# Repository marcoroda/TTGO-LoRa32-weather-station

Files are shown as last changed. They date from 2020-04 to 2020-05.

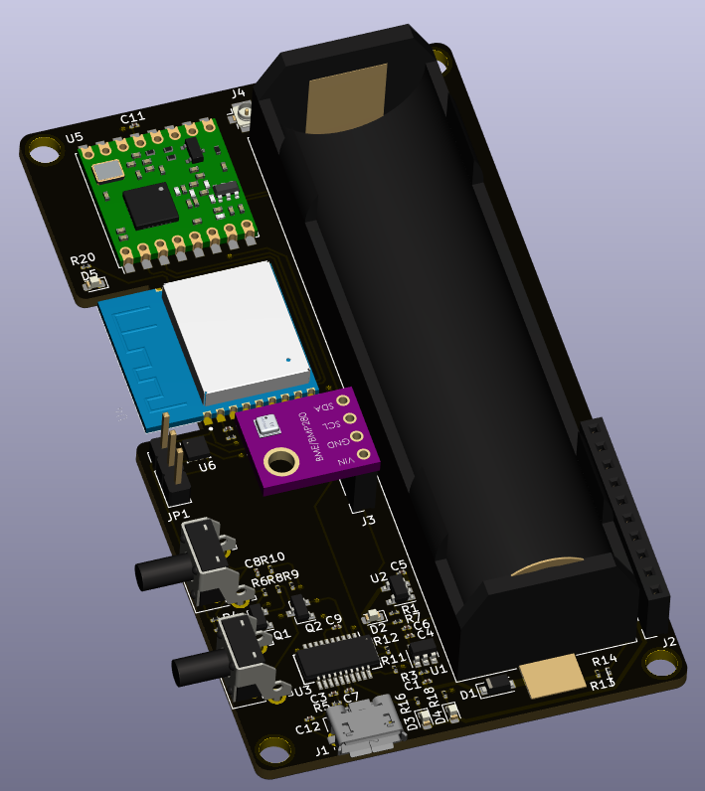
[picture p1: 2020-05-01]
hw/pcb/img/3d_pcb.png

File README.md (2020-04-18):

# ttgo-LoRa-weatherStation
TTGO board hooked up with BME280 and connected to TTN through LoRa.

* /hw : Hardware related (PCB, Schematics, 3D case, etc).
* /src : PlatformIO project.
* /node-RED : node-RED app retrieving LoRa payload from The Things Network

Project documentation [here](https://marcoroda.com/2020/04/12/TTGO-LORA-TTN.html)

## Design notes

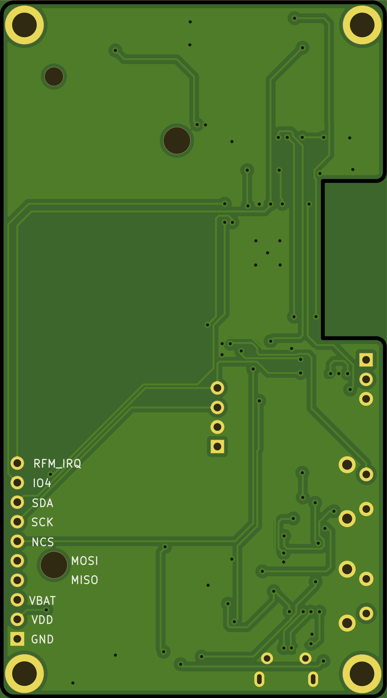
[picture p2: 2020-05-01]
hw/pcb/LoRa_node_WeatherStation/plot/LoRa_node_WeatherStation-Back.png

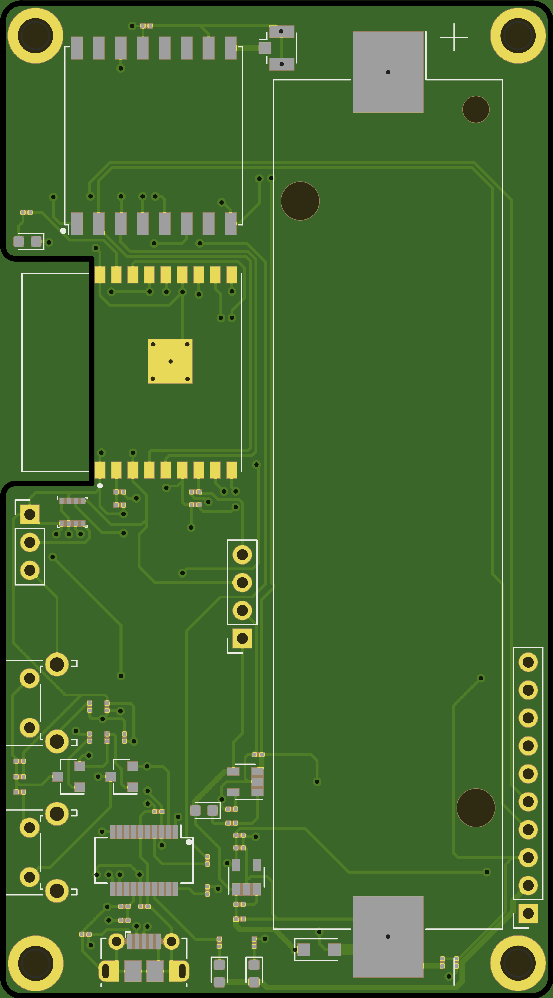
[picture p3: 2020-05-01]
hw/pcb/LoRa_node_WeatherStation/plot/LoRa_node_WeatherStation-Front.png

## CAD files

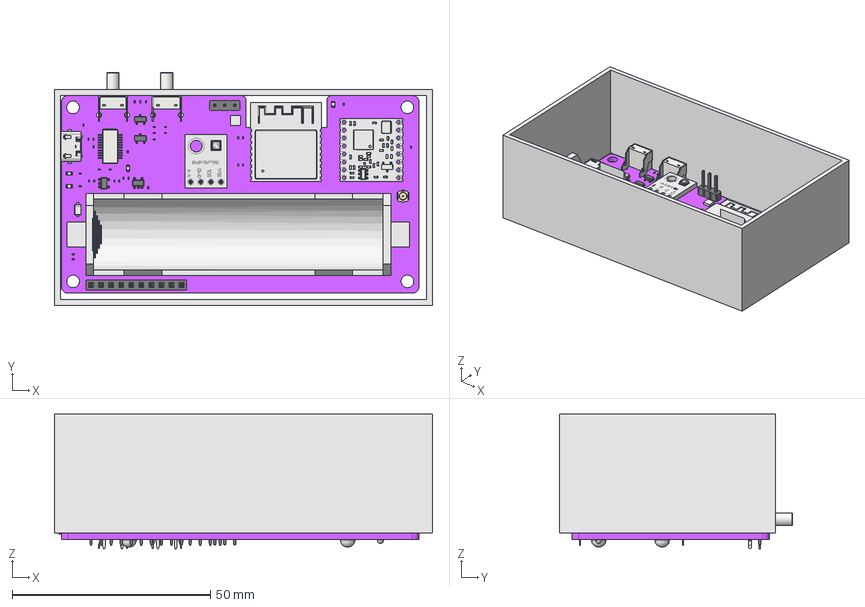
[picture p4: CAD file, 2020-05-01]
hw/3d_enclosure/3d_enclosure.FCStd
95.4 x 58.8 x 34.0 mm
Pcb
C7_C_0201_0603Metric_5EA9F067
BT1_BatteryHolder_Keystone_1042_1x18650_5EA9C623
C1_C_0201_0603Metric_5EA9C634
C2_C_0201_0603Metric_5EAA4A3B
C3_C_0201_0603Metric_5EA9C656
C5_C_0201_0603Metric_5EA9C678
C6_C_0201_0603Metric_5EA9C689
C8_C_0201_0603Metric_5EA9C6AB
C9_C_0201_0603Metric_5EA9C6BC
C10_C_0201_0603Metric_5EA9C6CD
C11_C_0201_0603Metric_5EA9C6DE
D1_D_SOD_123F_5EA9C6F7
D2_LED_0603_1608Metric_5EA9C70A
D3_LED_0603_1608Metric_5EA9C71D
D4_LED_0603_1608Metric_5EAA3DA1
D5_LED_0603_1608Metric_5EA9C743
J2_PinSocket_1x10_P254mm_Vertical_5EA9C781
J3_PinSocket_1x04_P254mm_Vertical_5EAA5ACD
J3_User Library-GY-BME280_5EAA5ACD[2]
JP1_PinHeader_1x03_P254mm_Vertical_5EA9C7B0
Q1_SOT_23_5EAA5330
Q2_SOT_23_5EA9C7DA
R1_R_0201_0603Metric_5EAA9D60
R2_R_0201_0603Metric_5EA9C7FC
R3_R_0201_0603Metric_5EA9C80D
R4_R_0201_0603Metric_5EAA4BE8
R5_R_0201_0603Metric_5EA9C82F
R6_R_0201_0603Metric_5EA9C840
R7_R_0201_0603Metric_5EA9C851
R8_R_0201_0603Metric_5EA9C862
R9_R_0201_0603Metric_5EA9C873
R10_R_0201_0603Metric_5EA9C884
R11_R_0201_0603Metric_5EA9C895
R12_R_0201_0603Metric_5EAA3F9B
R18_R_0201_0603Metric_5EAA3AF5
R17_R_0201_0603Metric_5EA9C8C8
R19_R_0201_0603Metric_5EA9C8D9
R20_R_0201_0603Metric_5EA9C8EA
R15_R_0201_0603Metric_5EA9C8FB
R13_R_0201_0603Metric_5EA9C90C
R14_R_0201_0603Metric_5EA9C91D
SW1_SW_Tactile_SPST_Angled_PTS645Vx83-2LFS_5EA9C943
SW2_SW_Tactile_SPST_Angled_PTS645Vx83-2LFS_5EAA43DF
U1_SOT_23_5_5EAA80A0
U2_SOT_23_5_5EA9C993
U3_SSOP_20_39x87mm_P0635mm_5EA9C9BC
U4_ESP-WROOM-02D--3DModel-STEP-56544_5EA9C9F2
U5_User Library-RFM96W_5EA9CA17[2]
U6_Bosch_LGA_8_25x25mm_P065mm_ClockwisePinNumbering_5EA9CA34
C4_C_0201_0603Metric_5EA9E3E5
J1_475890001_5EAA57F6[2]
R16_R_0201_0603Metric_5EAA3B67
J4_U.FL_Hirose_U.FL-R-SMT-1_Vertical_5EAA1C61
C12_C_0201_0603Metric_5EAA570B

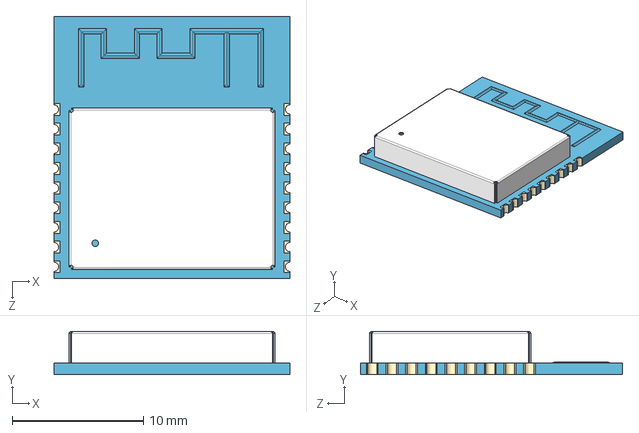
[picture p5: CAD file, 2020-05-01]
hw/3d_models/ESP-WROOM-02D--3DModel-STEP-56544.STEP
18.0 x 3.30 x 20.0 mm

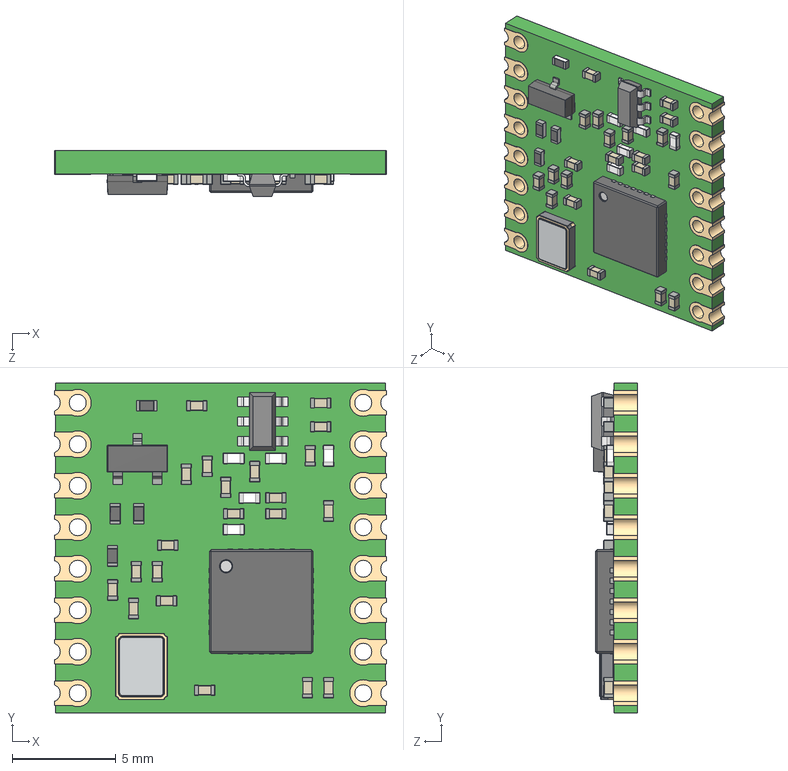
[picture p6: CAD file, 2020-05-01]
hw/3d_models/User Library-RFM96W/User Library-RFM96W.STEP
16.0 x 15.9 x 2.23 mm
Board
Cap0402 x 21
SW3dPS-inductor_0402_white x 5
SW3dPS-SOT-23-6
QFN28
TXC_7M
Res0402 x 4
User_Library-3-lead_sot23-3
Goldcontact x 16

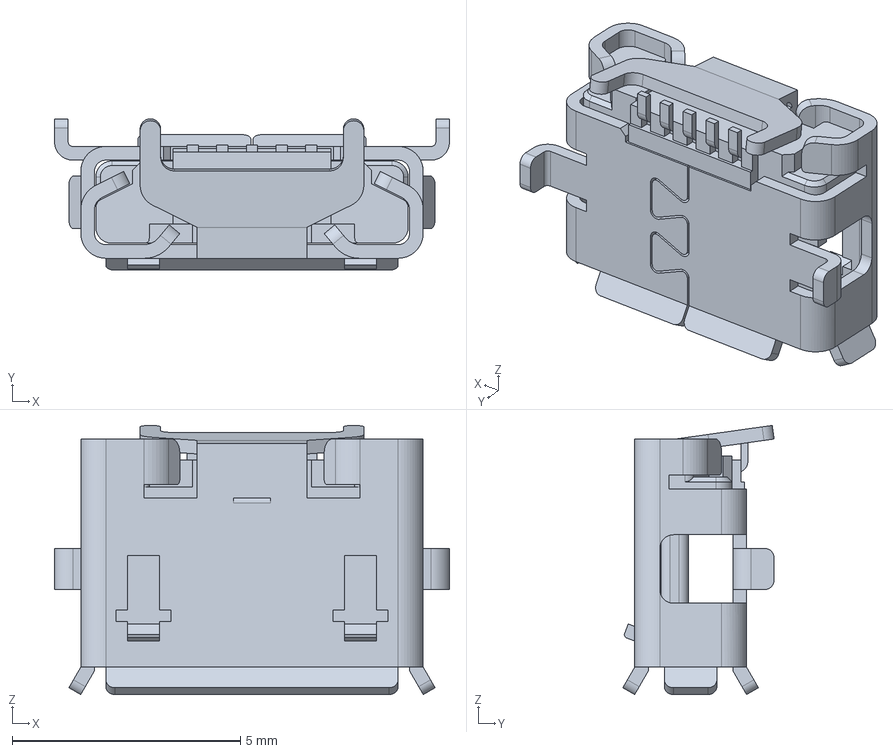
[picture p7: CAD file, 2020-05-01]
hw/3d_models/47589-0001_stp/475890001.stp
8.65 x 3.31 x 5.89 mm

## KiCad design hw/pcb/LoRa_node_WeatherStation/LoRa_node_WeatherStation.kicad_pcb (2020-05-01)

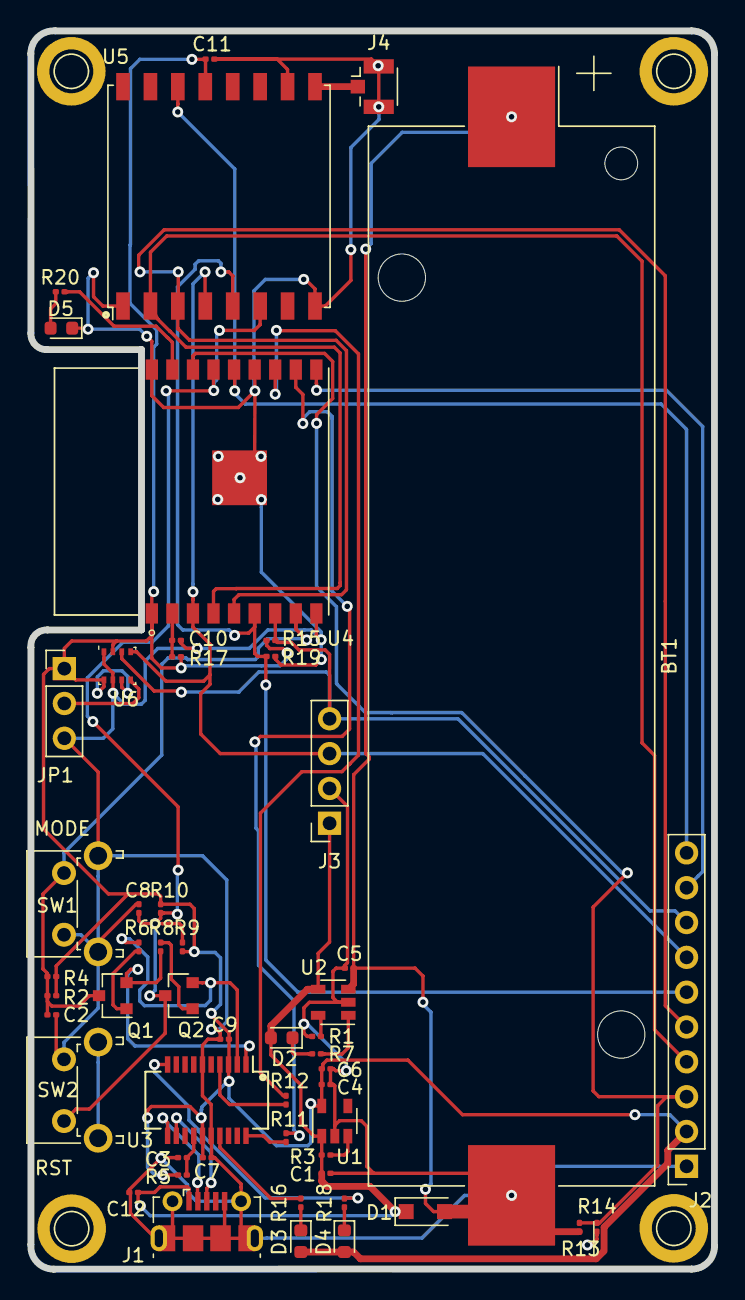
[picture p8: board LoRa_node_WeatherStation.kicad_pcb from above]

Board: 2 copper layers, 49.9 x 90.3 mm, 53 parts (0 on the bottom side), 38 nets.

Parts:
BT1: Battery_Cell; BatteryHolder_Keystone_1042_1x18650
C1, C4, C5, C9, C11: 10uF; C_0201_0603Metric
C2, C3, C7, C8, C10: 100nF; C_0201_0603Metric
C6: 1uF; C_0201_0603Metric
C12: 0.1uF; C_0201_0603Metric
D1: MBR120; D_SOD-123F
D2: ORANGE_LED; LED_0603_1608Metric
D3, D4: Blue_LED; LED_0603_1608Metric
D5: RED_LED; LED_0603_1608Metric
J1: USB_B_Micro; USB_Micro-B_Molex-105017-0001
J2: Conn_01x10; PinSocket_1x10_P2.54mm_Vertical
J3: BME breakout; PinSocket_1x04_P2.54mm_Vertical
J4: Conn_Coaxial; U.FL_Hirose_U.FL-R-SMT-1_Vertical
JP1: I2C slave Addr; PinHeader_1x03_P2.54mm_Vertical
Q1, Q2: BC848; SOT-23
R1, R2, R4, R5, R6, R8, R9, R10, R13, R14, R15, R17, R19: 10k; R_0201_0603Metric
R3: 100k; R_0201_0603Metric
R7, R16, R18, R20: 1k; R_0201_0603Metric
R11, R12: 470R; R_0201_0603Metric
SW1: MODE; SW_Tactile_SPST_Angled_PTS645Vx83-2LFS
SW2: RST; SW_Tactile_SPST_Angled_PTS645Vx83-2LFS
U1: SPX3819M5-L-3-3; SOT-23-5
U2: MCP73831-2-OT; SOT-23-5
U3: FT231XS; SSOP-20_3.9x8.7mm_P0.635mm
U4: ESP-WROOM-02; MODULE_ESP-WROOM-02
U5: RFM95W-868S2; HOPERF_RFM9XW_SMD
U6: BME280; Bosch_LGA-8_2.5x2.5mm_P0.65mm_ClockwisePinNumbering

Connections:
+BATT: BT1.1, C5.2, D1.2, R13.1, U2.3
/ADC: J2.3, R13.2, R14.1, U4.16
/ANT: J4.1, U5.9
/D+: J1.3, U3.12
/D-: J1.2, U3.11
/DTR: Q1.2, R8.1, U3.1
/IO0: C2.1, Q1.3, R2.1, R4.2, SW1.2, U4.8
/IO4: J2.9, U4.10
/IO16: R20.2, U4.17
/MISO: J2.4, U4.4, U5.2
/MOSI: J2.5, U4.5, U5.3
/RFM95_IRQ: J2.10, U4.14, U5.14
/RFM95_NSS: J2.6, R19.1, U4.6, U5.5
/RST: C8.1, Q2.3, R9.2, R10.1, SW2.1, U4.15, U5.6
/RTS: Q2.2, R6.1, U3.2
/RXD: R12.1, U4.12
/SCK: J2.7, J3.3, U4.3, U5.4, U6.4
/SDA: J2.8, J3.4, R15.2, U4.7, U6.3
/TXD: R11.1, U4.11
GND: BT1.2, C1.1, C2.2, C3.1, C4.1, C5.1, C6.1, C7.1, C8.2, C9.1, C10.2, C11.1, C12.1, D5.1, J1.5, J1.6, J2.1, J3.2, J4.2, JP1.3, R1.2, R14.2, R19.2, SW1.1, SW2.2, U1.2, U2.2, U3.6, U3.16, U4.9, U4.13, U4.18, U4.19, U5.1, U5.8, U5.10, U6.1, U6.7
unnamed: C3.2, R5.2, U3.14
unnamed: C10.1, R17.1, U4.2
unnamed: D2.1, R7.1
unnamed: D3.1, R16.1
unnamed: D4.1, R18.1
unnamed: D5.2, R20.1
unnamed: JP1.2, U6.5
unnamed: Q1.1, R6.2
unnamed: Q2.1, R8.2
unnamed: R1.1, U2.5
unnamed: R3.1, U1.3
unnamed: R7.2, U2.1
unnamed: R11.2, U3.20
unnamed: R12.2, U3.4
unnamed: R16.2, U3.17
unnamed: R18.2, U3.10
VBUS: C1.2, C12.2, D1.1, D2.2, J1.1, J3.1, R3.2, U1.1, U2.4
VDD: C4.2, C6.2, C7.2, C9.2, C11.2, D3.2, D4.2, J2.2, JP1.1, R2.2, R4.1, R5.1, R9.1, R10.2, R15.1, R17.2, U1.5, U3.3, U3.15, U4.1, U5.13, U6.2, U6.6, U6.8

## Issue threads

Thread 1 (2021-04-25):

Some problem in "Build"

xxxVincent-L, 2021-04-25:
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
Hi, Marco, my teammate and I are facing some problems in the process of "Build" in PlatformIO. We are now in China and we use the boards "heltec_wifi_lora_32". We usually solve one problem and then immediately another one comes up, which is frustrating. So we were wondering if you could give us some help

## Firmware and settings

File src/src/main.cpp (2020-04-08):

/*
    OTAA auth core code taken from otaa example
    - Reads sensor values from BME280 and sends it to TTN
    - ...
    
    author: Marco Roda, marcoroda.com
    date:   Mar 2020
*/

#include <Arduino.h>
#include "lmic.h"
#include <hal/hal.h>
#include <SPI.h>
#include <SSD1306.h>
#include "_device_config.h" /* Replace by device_config.h and add TTN keys to it */

#include "Bme280.h"

/* Blue LED on TTGO LILYGO -> To signal TX-ing*/
#define LEDPIN 2

/* OLED Display I2C pins and Reset */
#define OLED_I2C_ADDR 0x3C
#define OLED_RESET 16
#define OLED_SDA 4
#define OLED_SCL 15

/* OLED display instance */
SSD1306 display (OLED_I2C_ADDR, OLED_SDA, OLED_SCL);

/* Bme280 object */
Bme280 bme280;

#define NBR_MEAS            (3) /* Number or meas to send over LoRa to TTN */
#define LEN_MEAS_BYTES      (2) /* number of bytes it takes each sensor meas*/
#define LEN_PAYLOAD         ( NBR_MEAS * LEN_MEAS_BYTES )

/* Aux vars */
uint32_t counter    = 0;
uint8_t  cnt_mroda  = 0;
uint8_t addr = 0;
float_t sensor_val[5] = {0.0, 0.1, 0.2, 0.3, 0.4};

char TTN_response[30];


/* Get TTN credentials */
void os_getDevEui (u1_t* buf) { memcpy_P(buf, DEVEUI, 8);}
void os_getArtEui (u1_t* buf) { memcpy_P(buf, APPEUI, 8);}
void os_getDevKey (u1_t* buf) { memcpy_P(buf, APPKEY, 16);}

static osjob_t sendjob;

// Schedule TX every this many seconds (might become longer due to duty
// cycle limitations).
const unsigned TX_INTERVAL = 60;

// Pin mapping
const lmic_pinmap lmic_pins = {
    .nss = 18,
    .rxtx = LMIC_UNUSED_PIN,
    .rst = 14,
    .dio = {26, 33, 32}  /* Pins for the Heltec ESP32 Lora board/ TTGO Lora32 with 3D metal antenna */
};


float read_sensor(uint8_t addr)
{
    return sensor_val[addr];
}

void send_uptime_OLED(unsigned long time)
{
    display.drawString(0, 40, "Up Time in [min]: ");
    display.drawString(80, 40, String(time));
}

void send_sensor_val_OLED(uint8_t addr)
{
    display.drawString(0, 30, "Sensor Val : ");
    display.drawString(80, 30, String(read_sensor(addr)));
}

/*! @brief Returns the upTime for the uController
 *
 *  @param[out] scaled_time     upTime in minutes
 */
uint32_t get_time(void)
{
    uint32_t scaled_time = 0;
    scaled_time = (uint32_t) (millis() / 1000) / 60; // in minutes

    return scaled_time;
}

/*! @brief  Returns a pointer to the payload data to be sent over LoRa
 *
 */
uint8_t* gen_TX_msg(uint8_t incr)
{
    /* LoRa payload array message */
    static uint8_t payload_lora[LEN_PAYLOAD] = {0};

    /* Get sensor values */
    float temperature = bme280.getTemperature() + incr;
    float humidity    = bme280.getHumidity() + incr;
    float pressure    = bme280.getPressure() + incr;

    int16_t celciusInt  = temperature * 100; // convert to signed 16 bits integer
    payload_lora[0]     = celciusInt >> 8;
    payload_lora[1]     = celciusInt;

    int16_t humidityInt = humidity * 100;
    payload_lora[2]     = humidityInt >> 8;
    payload_lora[3]     = humidityInt;

    int16_t pressureInt = pressure    * 100;
    payload_lora[4]     = pressureInt >> 8;
    payload_lora[5]     = pressureInt;
    
    return payload_lora;
}


void do_send(osjob_t* j){

    // Check if there is not a current TX/RX job running
    if (LMIC.opmode & OP_TXRXPEND) {
        Serial.println(F("OP_TXRXPEND, not sending"));
    } else {
        /* Prepare upstream data transmission at the next possible time */
        
        // LMIC_setTxData2(1, (uint8_t*)&temperature, sizeof(float), 0);
        LMIC_setTxData2(1, gen_TX_msg(cnt_mroda), LEN_PAYLOAD, 0);
        cnt_mroda++;
        if(cnt_mroda == 20)
        {
            cnt_mroda = 0;
        }
        
        Serial.println(F("Sending uplink packet..."));
        digitalWrite(LEDPIN, HIGH);
        display.clear();
        display.drawString (0, 0, "Sending uplink packet...");
        display.drawString (0, 50, String (++counter));
        display.display ();
    }
    // Next TX is scheduled after TX_COMPLETE event.
}

void onEvent (ev_t event) {
    Serial.print(os_getTime());
    Serial.print(": ");
    switch(event)
    {
        case EV_TXCOMPLETE:
            Serial.println(F("EV_TXCOMPLETE (includes waiting for RX windows)"));
            display.clear();
            display.drawString (0, 0, "TX Done ...");

            if (LMIC.txrxFlags & TXRX_ACK) {
                Serial.println(F("Received ack"));
                display.drawString (0, 20, "Received ACK.");
            }

            if (LMIC.dataLen) {
                int i = 0;
                // data received in rx slot after tx
                Serial.print(F("Data Received: "));
                Serial.write(LMIC.frame+LMIC.dataBeg, LMIC.dataLen);
                Serial.println();
                Serial.println(LMIC.rssi);

                display.drawString (0, 9, "Received DATA.");
                for ( i = 0 ; i < LMIC.dataLen ; i++ )
                TTN_response[i] = LMIC.frame[LMIC.dataBeg+i];
                TTN_response[i] = 0;
                display.drawString (0, 22, String(TTN_response));
                display.drawString (0, 32, String(LMIC.rssi));
                display.drawString (64,32, String(LMIC.snr));
            }

                /* Schedule next transmission */
            os_setTimedCallback(&sendjob, os_getTime()+sec2osticks(TX_INTERVAL), do_send);
            digitalWrite(LEDPIN, LOW);
            display.drawString (0, 50, String (counter));
            
            /* get upTime and read sensor */
            send_uptime_OLED(get_time());
            send_sensor_val_OLED(addr);
            addr++;
            
            if (addr == 4)
            {
                addr = 0;
            }

            display.display ();
            // Schedule next transmission
            os_setTimedCallback(&sendjob, os_getTime()+sec2osticks(TX_INTERVAL), do_send);
            break;

        case EV_JOINING:
            Serial.println(F("EV_JOINING: -> Joining..."));
            display.drawString(0,16 , "OTAA joining...");
            
            /* get uptime and read sensor */
            send_uptime_OLED(get_time());
            send_sensor_val_OLED(addr);

            display.display();
            break;
        case EV_JOINED:
            Serial.println(F("EV_JOINED"));
            display.clear();
            display.drawString(0 , 0 ,  "Joined!");
            display.display();
            // Disable link check validation (automatically enabled
            // during join, but not supported by TTN at this time).
            LMIC_setLinkCheckMode(0);
            break;

        case EV_RXCOMPLETE:
            // data received in ping slot
            Serial.println(F("EV_RXCOMPLETE"));
            break;

        case EV_LINK_DEAD:
            Serial.println(F("EV_LINK_DEAD"));
            break;

        case EV_LINK_ALIVE:
            Serial.println(F("EV_LINK_ALIVE"));
            break;

        default:
            Serial.println(F("Unknown event"));
            break;
    }
}

void setup(void)
{
    Serial.begin(9600);
    delay(2500); /* Give the Serial comm sometime to pick up */
    Serial.println(F("Starting..."));

    /* Blue pin to signal TX */
    pinMode(LEDPIN,OUTPUT);

    /* Set up and reset the OLED Display */
    pinMode(OLED_RESET, OUTPUT);
    digitalWrite(OLED_RESET, LOW);
    delay(50);
    digitalWrite(OLED_RESET, HIGH);

    display.init();
    display.flipScreenVertically();
    display.setFont(ArialMT_Plain_10);

    display.setTextAlignment (TEXT_ALIGN_LEFT);

    display.drawString (0, 0, "Starting....");
    display.display ();

    /* BME280 init */
    // if( !bme280.init() )
    // {
    //     Serial.println(F("BME280 init failed!!"));
    // }
    // else
    // {
    //     bme280.printBmeValues();
    // }
    
    /* LMIC init */
    os_init();

    // Reset the MAC state. Session and pending data transfers will be discarded.
    LMIC_reset();
    LMIC_setClockError(MAX_CLOCK_ERROR * 1 / 100);
    
    /*  Set up the channels used by the Things Network, which corresponds
        to the defaults of most gateways. Without this, only three base
        channels from the LoRaWAN specification are used, which certainly
        works, so it is good for debugging, but can overload those
        frequencies, so be sure to configure the full frequency range of
        your network here (unless your network autoconfigures them).
        Setting up channels should happen after LMIC_setSession, as that
        configures the minimal channel set.
    */
    LMIC_setupChannel(0, 868100000, DR_RANGE_MAP(DR_SF12, DR_SF7),  BAND_CENTI);      // g-band
    LMIC_setupChannel(1, 868300000, DR_RANGE_MAP(DR_SF12, DR_SF7B), BAND_CENTI);      // g-band
    LMIC_setupChannel(2, 868500000, DR_RANGE_MAP(DR_SF12, DR_SF7),  BAND_CENTI);      // g-band
    LMIC_setupChannel(3, 867100000, DR_RANGE_MAP(DR_SF12, DR_SF7),  BAND_CENTI);      // g-band
    LMIC_setupChannel(4, 867300000, DR_RANGE_MAP(DR_SF12, DR_SF7),  BAND_CENTI);      // g-band
    LMIC_setupChannel(5, 867500000, DR_RANGE_MAP(DR_SF12, DR_SF7),  BAND_CENTI);      // g-band
    LMIC_setupChannel(6, 867700000, DR_RANGE_MAP(DR_SF12, DR_SF7),  BAND_CENTI);      // g-band
    LMIC_setupChannel(7, 867900000, DR_RANGE_MAP(DR_SF12, DR_SF7),  BAND_CENTI);      // g-band
    LMIC_setupChannel(8, 868800000, DR_RANGE_MAP(DR_FSK,  DR_FSK),  BAND_MILLI);      // g2-band
    
    /*  TTN defines an additional channel at 869.525Mhz using SF9 for class B
        devices' ping slots. LMIC does not have an easy way to define set this
        frequency and support for class B is spotty and untested, so this
        frequency is not configured here.
    */
    // Disable link check validation
    LMIC_setLinkCheckMode(0);

    // TTN uses SF9 for its RX2 window.
    LMIC.dn2Dr = DR_SF9;

    // Set data rate and transmit power for uplink (note: txpow seems to be ignored by the library)
    LMIC_setDrTxpow(DR_SF11,14);
    // LMIC_setDrTxpow(DR_SF7,14);

    /* Start job */
    do_send(&sendjob);     // Will fire up also the joinning to TTN
    //LMIC_startJoining();
}


/* App's While(True) */
void loop()
{
    os_runloop_once();
}

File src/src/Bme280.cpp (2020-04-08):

#include "Bme280.h"

/* Constructor and Destructor */
Bme280::Bme280() : temperature(32.12), humidity(70.3), pressure(101.325) { }
Bme280::~Bme280() {}

/* Init BME280 Sensor */
uint8_t Bme280::init(void)
{
    uint8_t ret = 1;

    Serial.println(F("BME280 init"));

    /* Default test Settings */
    uint8_t status;
    status = bme.begin();  
    if (!status) {
        Serial.println("Could not find a valid BME280 sensor, check wiring, address, sensor ID!");
        Serial.print("SensorID was: 0x"); Serial.println(bme.sensorID(),16);
        Serial.print("   ID of 0xFF probably means a bad address, a BMP 180 or BMP 085\n");
        Serial.print("   ID of 0x56-0x58 represents a BMP 280,\n");
        Serial.print("        ID of 0x60 represents a BME 280.\n");
        Serial.print("        ID of 0x61 represents a BME 680.\n");
        while (1) delay(10);
        ret = 1;
    }
    else
    {
        ret = 0;
        Serial.println(F("BME280 init done ... "));
    }
    
    Serial.println("-- BME280 Default Test --");
    Serial.println();
    
    return ret;
}

/* To test reading from BME280 */
void Bme280::printBmeValues()
{
    Serial.print("Temperature = ");
    Serial.print(bme.readTemperature());
    Serial.println(" *C");

    Serial.print("Pressure = ");
    Serial.print(bme.readPressure() / 100.0F);
    Serial.println(" hPa");

    Serial.print("Approx. Altitude = ");
    Serial.print(bme.readAltitude(SEALEVELPRESSURE_HPA));
    Serial.println(" m");

    Serial.print("Humidity = ");
    Serial.print(bme.readHumidity());
    Serial.println(" %");

    Serial.println();
}

/* GETS and SETs */
float Bme280::getTemperature(void) { return this->temperature; }
float Bme280::getHumidity   (void) { return this->humidity;    } 
float Bme280::getPressure   (void) { return this->pressure;    } 

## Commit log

2020-04-06 Added empty LoRa device_config.h (to be filled by user).
2020-04-08 Added sensor readings to a fancy Node-Red dashboard.
2020-04-08 Sending dummy sensor values: - Each sensor reading is sent using two bytes; - A message array is constructed with all dummy values (temperature, humidity and pressure)
2020-05-01 First draft PCB.
    [3d_enclosure.FCStd, 475890001.stp, ESP-WROOM-02D--3DModel-STEP-56544.STEP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]
